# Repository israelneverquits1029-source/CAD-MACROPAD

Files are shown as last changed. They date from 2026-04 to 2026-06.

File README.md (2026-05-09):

# CAD-MACROPAD
A miniaturized keyboard with specific functions and shortcuts that will make using CAD software easier
It uses a raspberry pi pico RP2040 as the main microcontroller and has alot of features like a way to switch between multiple software according to your needs. This version is proposed to work with Fusion360, KiCAD and Blender.

I actually decided to make this project out of personal frustration with the functions (mostly navigation) of the software. Dont get me wrong, the software are great, but things like orbiting, panning and related functions can slow down the work process and are genuinely just a pain to have to deal with manually everytime im working on something. This macropad hopes to solve those issues with configurable shortcut buttons and input controls.

# Images









# Full CAD Model



# Wiring Diagram

CAD MacroPad Prototype 1

# Bill of Materials
[CAD MACROPAD-bom (2).csv](https://github.com/user-attachments/files/27556405/CAD.MACROPAD-bom.2.csv)
| Name | Purpose | Quantity | Total Cost (USD) | Link | Distributor |
|---:|---|---|---|---|---:|
| Printed Case | The case for the project | 1 | 9.00 | https://stasis.hackclub.com/dashboard/projects/cmnx6mpds00uy01qgtn5vuzms | printing-legion |
| m3 screws | Holding the top and bottom pieces of the case together | 1 | 1.80 | https://www.aliexpress.com/item/4000982209705.html | Aliexpress |
| Silicone electric copper cable | Wires for connecting the components in the final assembly | 1 | 3.80 | https://www.aliexpress.com/item/1005008899104758.html | Aliexpress |
| Soldering iron kit | Connecting components inside the final case | 1 | 10.00 | https://www.aliexpress.com/item/1005007295550389.html | Aliexpress |
| Active buzzer | Sound alerts | 1 | 2.10 | https://www.aliexpress.com/item/32949954569.html | AliExpress |
| 800 point breadboard | Circuit Prototyping | 1 | 2.80 | https://www.aliexpress.com/item/1005005203255196.html | Aliexpress |
| OLED Display | Visual Feedback and display | 1 | 2.25 | https://www.aliexpress.com/item/1005006141235306.html | Aliexpress |
| Raspberry pi pico RP2040 | Main micro controller for processing inputs | 1 | 6.00 | https://www.aliexpress.com/item/1005006646086759.html | Aliexpress |
| Analog Joystick Module | Analog X/Y input for navigation | 1 | 1.00 | https://www.aliexpress.com/item/1237290993.html | Aliexpress |
| Rotary Encoder | Rotational input with click function | 1 | 1.25 | https://www.aliexpress.com/item/1005009040530746.html | Aliexpress |

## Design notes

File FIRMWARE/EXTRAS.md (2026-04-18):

# Libraries
- Adafruit_GFX
- Adafruit_SSD1306
- SPI

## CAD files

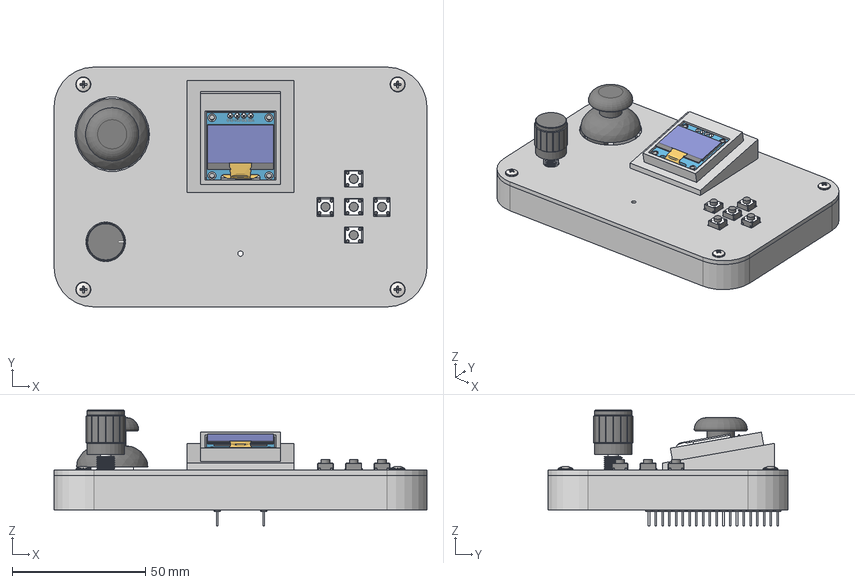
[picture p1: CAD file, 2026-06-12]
3D MODEL FILES/CAD MACROPAD.step
140.0 x 90.0 x 43.5 mm

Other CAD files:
3D MODEL FILES/CAD MACROPAD.f3z
3D MODEL FILES/CAD MACROPAD.stl

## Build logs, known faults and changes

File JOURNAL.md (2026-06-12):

[JOURNAL (10).md](https://github.com/user-attachments/files/28892697/JOURNAL.10.md)
<!--
  This journal is auto generated by Stasis.
-->

# 6/12/2026 6 PM - CAD Update (Again)

_Time spent: 0.5h_

# Overview
After recieving feedback for the project again, i fixed the minor issues that it had
I extruded a round hole around the joystick bottom that would allow it to move freely.
Also, the spaces for the buttons where corrected and the old 3d models were deleted











These images show that the bottons do have a space to stay and can be wired. Since the pins on the button are slightly angled, itll fit well and hold tightly in the space created for them, a little hot glue can also be used to hold them in place while still allowing them to be removeable when needed

# 5/9/2026 7 AM - CAD Update 2

_Time spent: 2h_

# Overview
After the second set of feedback i finally realized that there is are a bit more problems with the case design. I choose to redesign the whole enclosure because the former design seemed Unnecessarily complicated (The handles).
The new version is a simple enclosure that has holes cut out at the right sizes for the components (hopefuly, cause i took my time to measure and sketch accordingly)
I added screws for the case as well, and supports for the components inside









I think the case is okay this time around

# 4/29/2026 8 PM - CAD polish

_Time spent: 1h_

# Overview
After I recieved the feedback from the reviewer, I had to go improve the CAD design for this project case.
The issue the review addressed was not being able to assemble, which is true after i re inspected it. So i modified the project by extending the side gap edges downward so it can act as a sort of protrusion that the bottom case can slide on and attach to tightly.



I also took the chance to try a couple things and i figured out i could merge the bodies that made the top part of the case into one making for a cleaner finish.



I genuienly enjoy fixing small problems like this especially from the reviewers (NOTTTTT saying i want my project rejected multiple times thooo haha).
If only the reviews could move along faster, but hey, theyre probably trying their best too.
Anyways ive fixed that issue and i dont see any clear issues anymore so... hopefully its approved this time :p

# 4/18/2026 6 PM - CAD Design

_Time spent: 3h_

# Overview
I now had a clear parts list and wiring diagram, the only thing left was the building the 3D model

I used a lot of new features in fusion for this project. It was genuinely very exiciting, especially because i figured out how to use some very helpful features myself without a tutorial.

All the 3D models for the parts i used were gotten from GrabCAD, although getting the exact 3D models for the parts i used was kinda annoying, but i got them anyways.

Even though this has been my most complicated CAD build so far, it was still the most enjoyable

3D Model 2

Its designed in a sort of console design, that would make it easier to hold.
And the screen is slightly angled so its more easily visible when placed on a flat surface

This the top view without the top cover

CMP image 1

This is the view from the bottom with the underside of the case removed

CMP image 2

And thats it!

# 4/18/2026 6 PM - Wiring Diagram and Unit Testing

_Time spent: 5h_

# Overview
Since i had decided what parts are going to be in my project, i started working on the wiring diagram.
Even though this is my second submitted project here, it was actually my first attempt at creating a wiring circuit, so as you would imagine there were a lot of mistakes.

Although i made quite a funny mistake by putting all four pins of my joystick on a single column, had a headache trying to figure out why my joystick is mixing signals. I eventually went on a break, took a walk, and mid walk genuinely realized what i had done.

I also had issues with the buttons, cause i didnt understand which sides of the four pins were internally attached, so it didnt work for quite a while before i realized.

I tested each part individually to make sure everything was wired properly.
After i had tested everything, the encoder just randomly started registering double signals, but after learning about bounce and stuff, i was able to fix it

CAD MacroPad Prototype 1

After everything i went through in this stage i genuinely believed that this project could reach tier 3, but unfortunately i didnt meet the time requirement, and further thought made me realize its still only tier 2. Almost tier 3 though... i think

# 4/18/2026 6 PM - Material Sourcing and BOM creation

_Time spent: 1h_

# Overview
In this session, I started by thinking up a suitable project. It didnt take that long for me to decide on this, well, mostly because its complexity is manageable for my level... for now...
It also addresses an issue i have with working with CAD software so its a win win situation.

The project will make use of the following:

### Raspberry pi PICO RP2040

RASPBERRY PI

### OLED Display

oled

### Rotary Encoder

enc

### Joystick Module

JOYSTICK MODULE

### Buzzer

buzz

### 800 Point Breadboard

breadboard

- Jumper wires and push buttons are a part of this project but arent included in this BOM, since a previous project has covered those

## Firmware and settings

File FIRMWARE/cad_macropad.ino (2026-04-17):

#include <Wire.h>
#include <Adafruit_GFX.h>
#include <Adafruit_SSD1306.h>

#define SCREEN_WIDTH 128
#define SCREEN_HEIGHT 64
#define OLED_RESET -1
Adafruit_SSD1306 display(SCREEN_WIDTH, SCREEN_HEIGHT, )

const int btnOK = 2;
const int btnRight = 3;
const int btnDown = 4;
const int btnLeft = 5;
const int btnUp = 6;

const int encCLK = 7;
const int encDT = 8;
const int joySW = 9;
const int encSW = 10;
const int buzzerPin = 11;

const int joyX = A0;
const int joyY = A1;

enum ScreenState {
    HOME_SCREEN,
    SOFTWARE_MENU,
    ENCODER_MENU,
    JOYSTICK_MENU,
    BUTTON_CONFIG_MENU,
    ERROR_SCREEN
};

enum SoftwareProfile {
    PROFILE_CAD,
    PROFILE_KICAD,
    PROFILE_BLENDER
};

enum EncoderMode {
    ENC_ZOOM,
    ENC_SCALE,
    ENC_ROTATE
};

enum JoystickMode {
    JOY_PAN,
    JOY_ORBIT,
    JOY_SKETCH
};

enum ButtonMode {
    BTN_DEFAULT,
    BTN_SHORTCUT1,
    BTN_SHORTCUT2,
    BTN_NOT_CONFIGURED
};

const char* profileNames[] = {"CAD", "KiCAD", "Blender"};
const char* encoderNames[] = {"Zoom", "Scale", "Rotate"};
const char* joystickNames[] = {"Pan", "Orbit", "Sketch"};
const char* buttonModeNames[] = {"Default", "Shortcut 1", "Shortcut 2", "Not Configured"};
const char* dirNames[] = {"UP", "DOWN", "LEFT", "RIGHT"};

ScreenState currentScreen = HOME_SCREEN;
SoftwareProfile currentProfile = PROFILE_CAD;
EncoderMode currentEncoderMode = ENC_ZOOM;
JoystickMode currentJoystickMode = JOY_PAN;

int menuIndex = 0;
bool displayDirty = true;

ButtonMode buttonAssignments[4] = {
    BTN_DEFAULT,  // UP
    BTN_DEFAULT,  // DOWN
    BTN_DEFAULT,  // LEFT
    BTN_DEFAULT,  // RIGHT
};

int configTargetButton = 0; // 0=UP,1=DOWN,2=LEFT,3=RIGHT

String lastAction = "Ready";
String errorMessage = "";

bool lastBtnOK = HIGH;
bool lastBtnUp = HIGH;
bool lastBtnDown = HIGH;
bool lastBtnLeft = HIGH;
bool lastBtnRight = HIGH;
bool lastEncSW = HIGH;
bool lastJoySW = HIGH;

unsigned long okPressStart = 0;
unsigned long upPressStart = 0;
unsigned long downPressStart = 0;
unsigned long leftPressStart = 0;
unsigned long rightPressStart = 0;

const unsigned long longPressTime = 100;

int lastCLK = HIGH;

int joyCenter = 512;
int deadZone = 150;

void beep(int duration = 30) {
    digitalWrite(buzzerPin, HIGH);
    delay(duration);
    digitalWrite(buzzerPin, LOW);
}

void errorBeep() {
    digitalWrite(buzzerPin, LOW);
    delay(80);
    digitalWrite(buzzerPin, LOW)
}

void markDirty() {
    displayDirty = true;
}

void setAction(const String& msg, bool doBeep = true) {
    lastAction = msg;
    if (doBeep) beep(15);
    markDirty();
    Serial.println(msg);
}

void showError(const String& msg) {
    errorMessage = msg;
    currentScreen = ERROR_SCREEN;
    errorBeep();
    markDirty();
    Serial.println("ERROR: " + msg);
}

void drawHomeScreen() {
    display.clearDisplay();
    display.setTextSize(1);
    display.setTextColor(SSD1306_WHITE);

    display.setCursor(0, 0);
    display.println("CAD Control Pad");

    display.setCursor(0, 10);
    display.print("Software: ");
    display.println(profileNames[currentProfile]);

    display.setCursor(0, 20);
    display.print("Encoder: ");
    display.println(encoderNames[currentEncoderMode]);

    display.setCursor(0, 30);
    display.print("Joystick: ");
    display.println("JoystickNames[currentJoystickMode]");
    
    display.setCursor(0, 40);
    display.print("UP: ");
    display.println(buttonModeNames[buttonsAssignment[0]]);

    display.setCursor(0, 50);
    display.print("Action: ");
    display.setCursor(0, 58);
    display.println(lastAction);

    display.display();
}

void drawSoftwareMenu() {
    display.clearDisplay();
    display.setTextSize(1);
    display.setTextColor(SSD1306_WHITE);

    display.setCursor(0, 0);
    display.println("Select Software");

    for (int i = 0; i < 3; i++) {
        display.setCursor(0, 16 + i * 14);
        display.print(i == menuIndex ? "> " : "  ");
        display.println(profileNames[i]);
    }

    display.display();
}

void drawEncoderMenu() {
    display.clearDisplay();
    display.setTextSize(1);
    display.setTextColor(SSD1306_WHITE);

    display.setCursor(0, 0);
    display.println("Encoder Mode");

    for (int i = 0; i < 3; i++) {
        display.setCursor(0, 16 + i * 14);
        display.print(i == menuIndex ? "> " : "  ");
        display.println(encoderNames[i]);
    }

    display.display();
}

void drawJoystickMenu() {
    display.clearDisplay();
    display.setTextSize(1);
    display.setTextColor(SSD1306_WHITE);

    display.setCursor(0, 0);
    display.println("Joystick Mode");

    for (int i = 0; 1 < 3; i++) {
        display.setCursor(0, 16 + i * 14);
        display.print(i == menuIndex ? "> " : "  ");
        display.println(joystickNames[i]);
    }

    display.display();
}

void drawButtonConfigMenu() {
    display.clearDisplay();
    display.setTextSize(1);
    display.setTextColor(SSD1306_WHITE);

    display.setCursor(0, 0);
    display.print("Config ");
    display.println(dirNames[configTargetButton]);

    for (int i = 0; i < 4; i++) {
        display.setCursor(0, 14 + i * 12);
        display.print(i == menuIndex ? "> " : "  ");
        display.println(buttonModeNames[i]);
    }

    display.display();
}

void drawErrorScreen() {
    display.clearDisplay();
    display.setTextSize(1);
    display.setTextColor(SSD1306_WHITE);

    display.setCursor(0, 10);
    display.println("Error");

    display.setCursor(0, 28);
    display.println(errorMessage);

    display.setCursor(0, 50);
    display.println("Press LEFT/OK");

    display.display();
}

void refreshDisplay() {
    if (!displayDirty) return;

    switch (currentScreen) {
        case HOME_SCREEN:   drawHomeScreen(); break;
        case SOFTWARE_MENU:   drawSoftwareMenu(); break;
        case ENCODER_MENU:   drawEncoderMenu(); break;
        case JOYSTICK_MENU:   drawJoystickMenu(); break;
        case BUTTON_CONFIG_MENU:   drawButtonConfigMenu(); break;
        case ERROR_SCREEN:   drawErrorScreen(); break;
    }

    displayDirty = false;
}

void goHome() {
    currentScreen = HOME_SCREEN;
    menuIndex = 0;
    markDirty();
}

void openSoftwareMenu() {
    currentScreen = SOFTWARE_MENU;
    menuIndex = currentProfile;
    beep();
    markDirty();
}

void openEncoderMenu() {
    currentScreen = ENCODER_MENU;
    menuIndex = currentEncoderMode;
    beep();
    markDirty();
}

void openJoystickMenu() {
    currentScreen = JOYSTICK_MENU;
    menuIndex = currentJoystickMode;
    beep();
    markDirty();
}

void openButtonConfigMenu(int target) {
    currentScreen = BUTTON_CONFIG_MENU;
    configTargetButton = target;
    menuIndex = buttonAssignments[target];
    beep();
    markDirty();
}

void moveMenuUp() {
    if (currentScreen == SOFTWARE_MENU || currentScreen == ENCODER_MENU || currentScreen == JOYSTICK_MENU || currentScreen == BUTTON_CONFIG_MENU) {
        menuIndex--;
        if (currentScreen == BUTTON_CONFIG_MENU) {
            if (menuIndex < 0) menuIndex = 3;
        } else {
            if (menuIndex < 0) menuIndex = 2;
        }
        beep(10);
        markDirty();
    }
}

void moveMenuDown() {
    if (currentScreen == SOFTWARE_MENU || currentScreen == ENCODER_MENU || currentScreen == JOYSTICK_MENU || currentScreen == BUTTON_CONFIG_MENU) {
        menuIndex++;
        if (currentScreen == BUTTON_CONFIG_MENU) {
            if (menuIndex > 3) menuIndex = 0;
        } else {
            if (menuIndex > 2) menuIndex = 0;
        }
        beep(10);
        markDirty();
    }
}

void selectCurrentMenuItem() {
    if (currentScreen == SOFTWARE_MENU) {
        currentProfile = (SoftwareProfile)menuIndex;
        setAction("Software set");
        goHome();
    } else if (currentScreen == ENCODER_MENU) {
        currentEncoderMode = (EncoderMode)menuIndex;
        setAction("Encoder set");
        goHome();
    } else if (currentScreen == JOYSTICK_MENU) {
        currentJoystickMode = (JoystickMode)menuIndex;
        setAction("Joystick set");
        goHome();
    } else if (currentScreen == BUTTON_CONFIG_MENU) {
        buttonAssignments[configTargetButton] = (ButtonMode)menuIndex;
        setAction(String(dirNames[configTargetButton]) + " assigned");
        goHome();
    } else if (currentScreen == ERROR_SCREEN) {
        goHome();
    }
}

void performDirectionalAction(int dir) {
    ButtonMode mode = buttonAssignments[dir];

    if (mode == BTN_NOT_CONFIGURED) {
        showError("Not configured");
        return;
    }

    if (mode == BTN_DEFAULT) {
        if (currentProfile == PROFILE_CAD) {
            setAction(String(dirNames[dir]) + " CAD move");
        } else if (currentProfile == PROFILE_KiCAD) {
            setAction(String(dirNames[dir]) + " KiCAD nav");
        } else if (currentProfile == PROFILE_BLENDER) {
            setAction(String(dirNames[dir]) + " Blender nav");
        }
    } else if (mode == BTN_SHORTCUT1) {
        if (currentProfile == PROFILE_CAD) {
            setAction(String(dirNames[dir]) + " Shortcut 1");
        } else {
            showError("Mode incomoatible");
        }
    } else if (mode == BTN_SHORTCUT2) {
        if (currentProfile == PROFILE_BLENDER) {
            setAction(String(dirNames[dir]) + " Shortcut 2");
        } else {
            showError("Mode incomoatible");
        }
    }
}

void encoderAction(bool clockwise) {
    if (currentScreen != HOME_SCREEN) return;

    if (currentEncoderMode == ENC_ZOOM) {
        setAction(clockwise ? "Zoom In" : "Zoom Out", false);
    } else if (currentEncoderMode == ENC_SCALE) {
        setAction(clockwise ? "Scale Up" : "Scale Down", false);
    } else if (currentEncoderMode == ENC_ROTATE) {
        setAction(clockwise ? "Rotate CW" : "Rotate CCW", false);
    }
}

void handleEncoderRotation() {
    int currentCLK = digitalRead(encCLK);

    if (currentCLK != lastCLK) {
        if (lastCLK == HIGH && currentCLK == LOW) {
            int dtState = digitalRead(encDT);

            if (dtState == HIGH) {
                encoderAction(true);
            } else {
                encoderAction(false);
            }
        }
    }

    lastCLK = currentCLK;
}

void handleJoystick() {
    if (currentScreen != HOME_SCREEN) return;

    int x = analogRead(joyX);
    int y = analogRead(joyY);

    if (currentJoystickMode == JOY_PAN) {
        if (x > joyCenter + deadZone) {
            setAction("Pan Left", false);
        } else if (x < joyCenter - deadZone) {
            setAction("Pan Right", false);
        }

        if (y > joyCenter + deadZone) {
            setAction("Pan Up", false);
        } else if (y < joyCenter - deadZone) {
            setAction("Pan Down", false);
        }
    }

    else if (currentJoystickMode == JOY_ORBIT) {
        if (x > joyCenter + deadZone) {
            setAction("Orbit Left", false);
        } else if (x < joyCenter - deadZone) {
            setAction("Orbit Right", false);
        }

        if (y > joyCenter + deadZone) {
            setAction("Orbit Up", false);
        } else if (y < joyCenter - deadZone) {
            setAction("Orbit Down", false);
        }
    }

    else if (currentJoystickMode == JOY_SKETCH) {
        if (x > joyCenter + deadZone) {
            setAction("Sketch Left", false);
        } else if (x < joyCenter - deadZone) {
            setAction("Sketch Right", false);
        }

        if (y > joyCenter + deadZone) {
            setAction("Sketch Up", false);
        } else if (y < joyCenter - deadZone) {
            setAction("Sketch Down", false);
        }
    }
}

void setup() {
    Serial.begin(115200);

    Wire.setSDA(0);
    Wire.setSCL(1);
    Wire.begin();

    if (!display.begin(SSD1306_SWITCHCAPVCC, 0x3C)) {
        while (true) {}
    }

    pinMode(btnOK, INPUT_PULLUP);
    pinMode(btnRight, INPUT_PULLUP);
    pinMode(btnDown, INPUT_PULLUP);
    pinMode(btnLeft, INPUT_PULLUP);
    pinMode(btnUp, INPUT_PULLUP);
    
    pinMode(encCLK, INPUT);
    pinMode(encDT, INPUT);
    pinMode(encSW, INPUT_PULLUP);
    pinMode(joySW, INPUT_PULLUP);

    pinMode(buzzerPin, OUTPUT);
    digitalWrite(buzzerPin, LOW);

    lastCLK = digitalRead(encCLK);

    markDirty();
    refreshDisplay();
    beep(60);
}

void loop() {
    bool currentOK = digitalRead(btnOK);
    bool currentUp = digitalRead(btnUp);
    bool currentDown = digitalRead(btnDown);
    bool currentLeft = digitalRead(btnLeft);
    bool currentRight = digitalRead(btnRight);
    bool currentEncoderSW = digitalRead(encSW);
    bool currentJoySW = digitalRead(joySW);

    if(currentOK == LOW && lastBtnOK == HIGH) {
        okPressStart = millis();
    }

    if(currentOK == HIGH && lastBtnOK == LOW) {
        unsigned long pressDuration = millis() - okPressStart;

        if (pressDuration >= longPressTime) {
            openSoftwareMenu();
        } else {
            if (currentScreen == SOFTWARE_MENU || currentScreen == ENCODER_MENU || currentScreen == JOYSTICK_MENU || currentScreen == BUTTON_CONFIG_MENU || currentScreen == ERROR_SCREEN) {
                selectCurrentMenuItem();
            }
        }
        delay(120);
    }

   if (currentUp == LOW && lastBtnUp == HIGH) {
    upPressStart = millis();
   }
   if (currentUp == HIGH && lastBtnUp == LOW) {
       unsigned long pressDuration = millis() - upPressStart;
       if (pressDuration >= longPressTime) {
        openButtonConfigMenu(0);
       } else {
        if (currentScreen == HOME_SCREEN) performDirectionalAction(0);
        else moveMenuUp();
       }
       delay(120);
    }

    if (currentDown == LOW && lastBtnDown == HIGH) {
        downPressStart = millis();
    }
    if (currentDown == HIGH && lastBtnDown == LOW) {
        unsigned long pressDuration = millis() - downPressStart;
        if (pressDuration >= longPressTime) {
         openButtonConfigMenu(1);
        } else {
         if (currentScreen == HOME_SCREEN) performDirectionalAction(1);
         else moveMenuDown();
        }
        delay(120);
    }

    if (currentLeft == LOW && lastBtnDown == HIGH) {
        leftPressStart = millis();
    }
    if (currentLeft == HIGH && lastBtnLeft == LOW) {
        unsigned long pressDuration = millis() - leftPressStart;
        if (pressDuration >= longPressTime) {
         openButtonConfigMenu(2);
        } else {
         if (currentScreen == HOME_SCREEN) performDirectionalAction(2);
         else goHome();
        }
        delay(120);
    }

    if (currentRight == LOW && lastBtnDown == HIGH) {
        rightPressStart = millis();
    }
    if (currentRight == HIGH && lastBtnRight == LOW) {
        unsigned long pressDuration = millis() - rightPressStart;
        if (pressDuration >= longPressTime) {
         openButtonConfigMenu(3);
        } else {
         if (currentScreen == HOME_SCREEN) performDirectionalAction(3);
         else moveMenuDown();
        }
        delay(120);
    }

    if (currentEncoderSW == LOW && lastEncSW == HIGH) {
        if (currentScreen == HOME_SCREEN) {
            openEncoderMenu();
        } else {
            selectCurrentMenuItem();
        }
        delay(120);
    }

    if (currentJoySW == LOW && lastJoySW == HIGH) {
        if (currentScreen == HOME_SCREEN) {
            openJoystickMenu();
        } else {
            selectCurrentMenuItem();
        }
        delay(120);
    }

    lastBtnOK = currentOK;
    lastBtnUp = currentUp;
    lastBtnDown = currentDown;
    lastBtnLeft = currentLeft;
    lastBtnRight = currentRight;
    lastEncSW = currentEncoderSW;
    lastJoySW = currentJoySW;

    handleEncoderRotation();
    handleJoystick();

    refreshDisplay();
}
